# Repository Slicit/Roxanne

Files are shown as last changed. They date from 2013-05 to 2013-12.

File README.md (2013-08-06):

Roxanne
=======

Roxanne is a FFF 3D Printer, Inspired by Reprap, Foldarap, And MendelMax

A 3D PDF is available in /manual (3D Assembly & PDF not up-to-date)

=======

*STL Print list, release 1.0*

- (1)Axe_Guide_160mm.STL
- (1)Axe_Guide_160mm_Bearing_Vertical.STL
- (1)Bowden_JHead_Compatible.STL
- (1)Direct_Drive_Extruder.STL
- (1)Direct_Drive_Tightner.stl
- (1)Endstop_Holder_Profile_Y.STL
- (1)Rotary_LCD.STL
- (1)Triple_Fan_Holder_40mm.STL
- (1)XZ_End_Ajustable.STL
- (1)XZ_End_Idler.STL
- (1)X_Carriage.STL
- (1)X_Motor_Plate.STL
- (1)Y_Motor_Bottom.STL
- (1)Y_Motor_Top.STL
- (2)Angle_33.STL
- (2)Angle_57.stl
- (2)Captive_M6_Nut.STL
- (2)Endstop_Holder_Profile_XZ.STL
- (2)Fan_Support_40mm.STL
- (2)X_End_Idler.STL
- (2)Z_Motor_Plate.STL
- (4)LM10UU_Holder.STL
- (4)Print_Surface_Holder.STL

=======
Thanks to:
- lv-esad
- wooz_

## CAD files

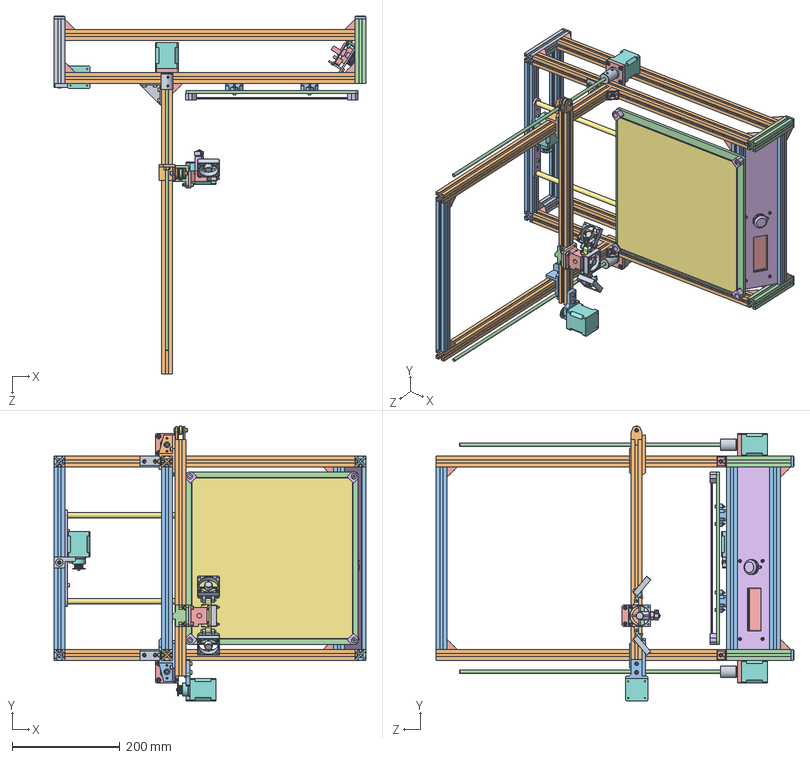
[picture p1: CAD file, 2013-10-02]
sources/solidworks/Roxanne_r2.SLDASM
580.0 x 511.0 x 665.0 mm
Profil_Alu_20x20_2-120mm x 2
Profil_Alu_20x20_540mm x 6
Profil_Alu_20x20_340mm x 5
Profil_Alu_20x20_120mm x 2
Z_Motor_Plate x 2
Axe_Guide_160mm
Rod_500mm x 2
Nema17_48mm x 4
Z_Coupler_5_6 x 2
Profil_Alu_20x20_440mm
Stamp_Foot x 4
6mm_Threaded_Rod_Simple x 2
Angle_2020 x 20
LCD_Plate
socket head cap screw_am x 101
Pulley x 2
Angle_2040 x 2
X_End_Idler x 2
X_Motor_Plate_v2
instrument ball bearing_68_am
RRD_LCD_Smart_Controller
Rotary_LCD
hex nut style 2_am x 4
Reset_Button
Axe_Guide_160mm_Bearing_Vertical
LM10UU x 4
LM10UU_Holder_Higher x 4
Wood_Bed_Simplified
hex nut style 1_am x 20
Glass_Holder x 4
Mirror_Build_Plate
Y_Motor_Bottom
Y_Motor_Top
X-End-Idler-V1
X-End-Motor-V1
X-Carriage-V4
Bowden_JHead_V2
JHead_MKVB
Triple_Fan_Holder_40mm
Support_Ventilateur_1 x 2
Fan_40mm x 3

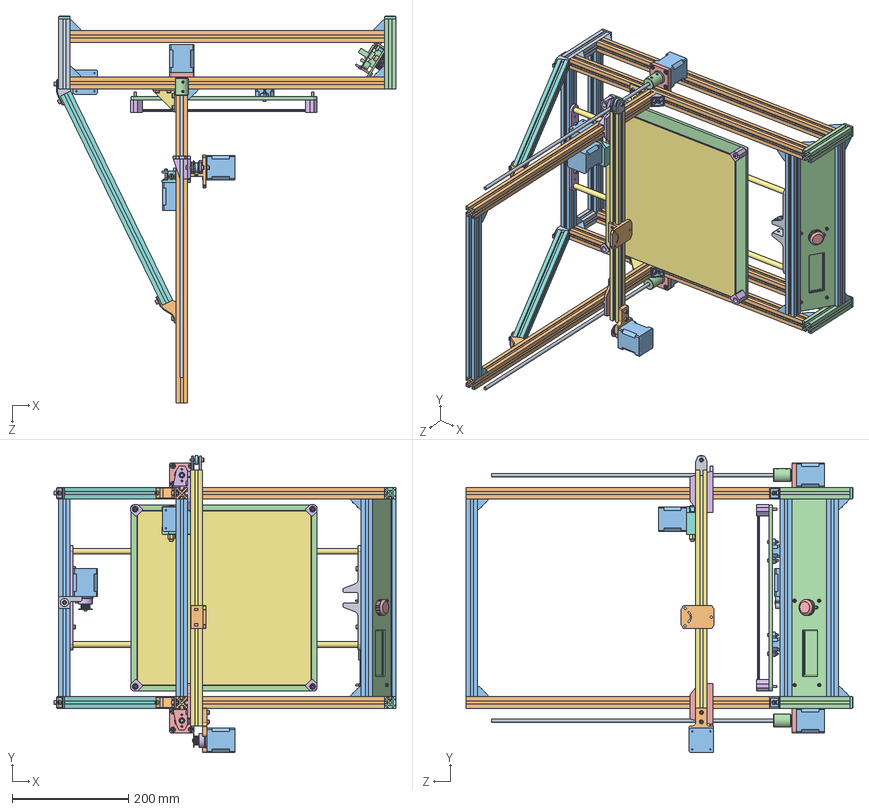
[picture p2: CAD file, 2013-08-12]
sources/solidworks/Roxanne_v1.SLDASM
587.9 x 511.0 x 665.0 mm
Profil_Alu_20x20_2-120mm x 2
Profil_Alu_20x20_540mm x 6
Profil_Alu_20x20_340mm x 5
Profil_Alu_20x20_120mm x 2
Z_Motor_Plate x 2
Axe_Guide_160mm
Rod_500mm x 2
Profil_Alu_20x20_400mm x 2
Angle_33 x 2
Angle_57 x 2
Nema17_48mm x 5
Z_Coupler_5_6 x 2
Router_XZ_Left_V2
Router_XZ_Right_V2
Profil_Alu_20x20_440mm
Stamp_Foot x 4
6mm_Threaded_Rod_Simple x 2
X_Carriage_v3
Angle_2020 x 20
LCD_Plate
socket head cap screw_am x 107
Pulley x 2
Angle_2040 x 2
Direct_Drive_Extruder_v2
X_End_Idler x 2
X_Motor_Plate_v2
instrument ball bearing_68_am
RRD_LCD_Smart_Controller
Rotary_LCD
hex nut style 2_am x 4
Pneufit_4mm_OD
Reset_Button
Axe_Guide_160mm_Bearing_Vertical
LM10UU x 4
LM10UU_Holder_Higher x 4
Wood_Bed_Simplified
hex nut style 1_am x 8
Glass_Holder x 4
Mirror_Build_Plate
Y_Motor_Bottom
Y_Motor_Top

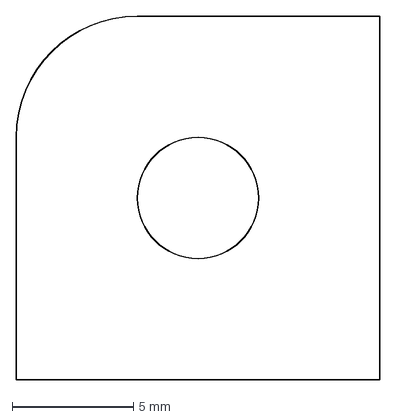
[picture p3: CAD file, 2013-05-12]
sources/lasercut/Spacer.DXF
15.0 x 15.0 mm

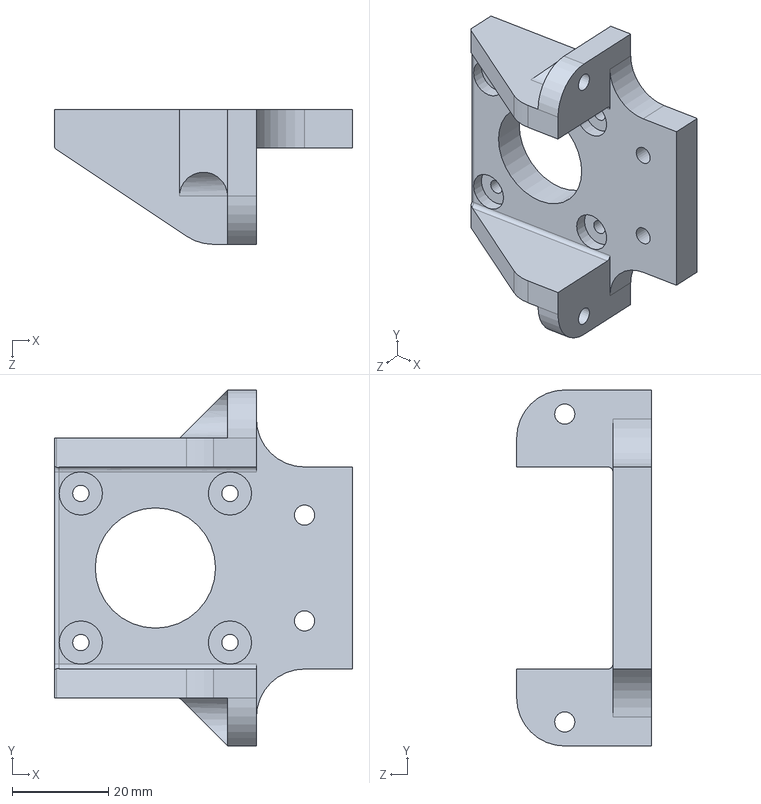
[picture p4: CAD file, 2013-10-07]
sources/solidworks/Z_Motor_Plate_v2.SLDPRT
62.0 x 74.0 x 28.0 mm

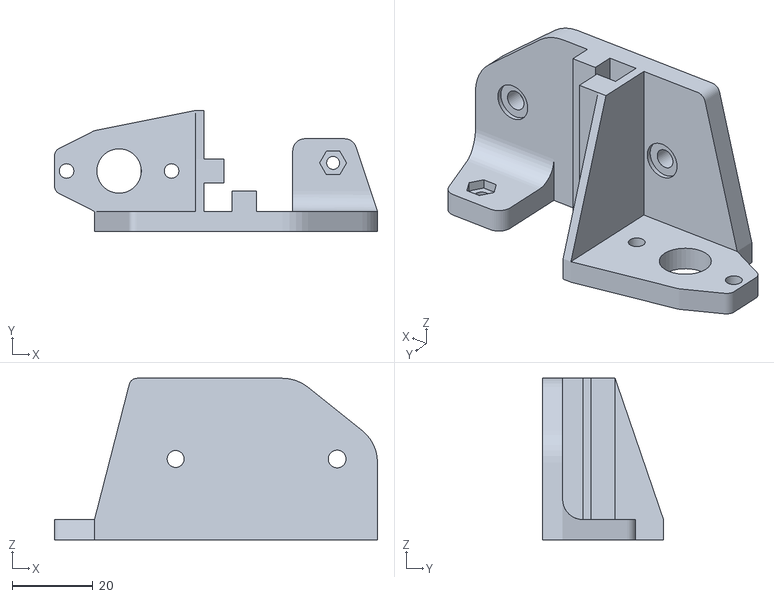
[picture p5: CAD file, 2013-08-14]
sources/stl/rev1/Router_XZ_Left_V2_Larger.STL
80.0 x 30.0 x 40.0

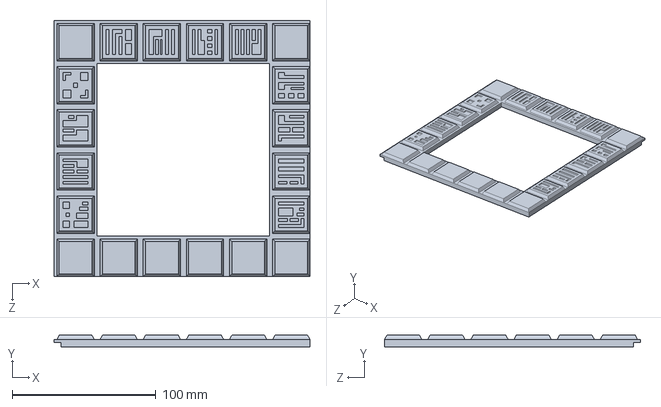
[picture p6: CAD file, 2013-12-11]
sources/stl/telchak.SLDPRT
178.0 x 8.00 x 178.0 mm

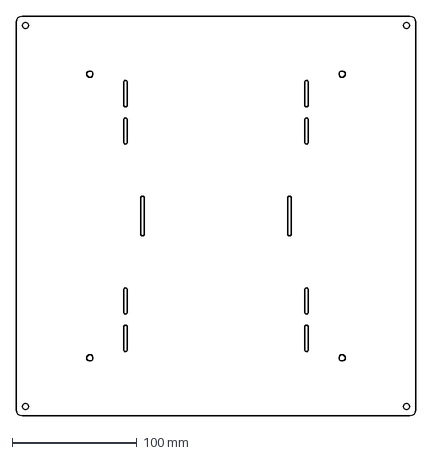
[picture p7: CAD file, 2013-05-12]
sources/lasercut/Bed.DXF
320.0 x 320.0 mm

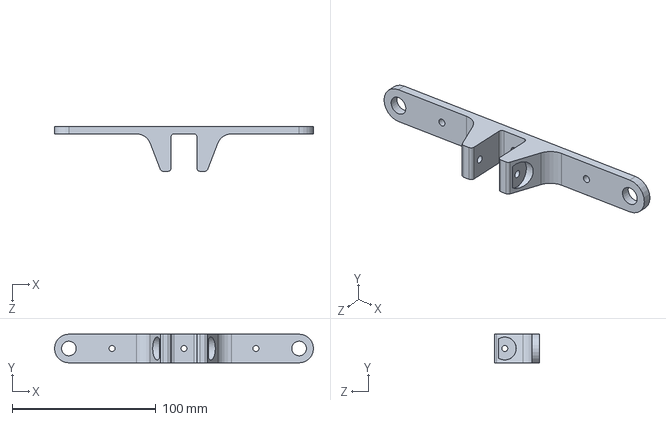
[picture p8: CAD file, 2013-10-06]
sources/solidworks/Axe_Guide_160mm_Bearing_Vertical.SLDPRT
180.0 x 20.0 x 31.0 mm

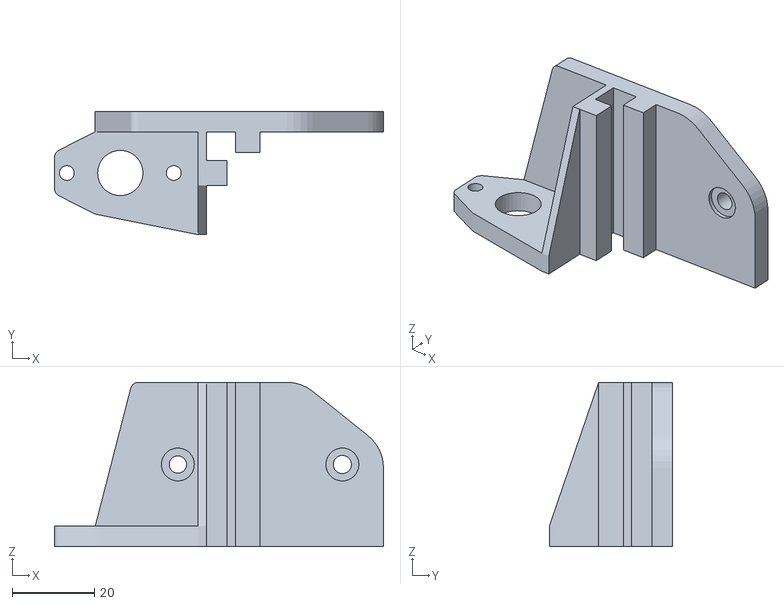
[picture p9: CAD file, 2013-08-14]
sources/stl/rev1/Router_XZ_Right_V3_Larger.STL
80.0 x 30.0 x 40.0

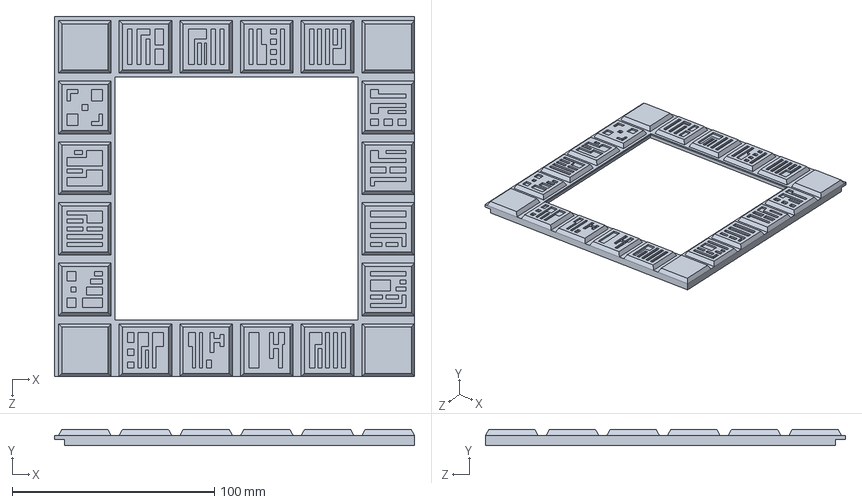
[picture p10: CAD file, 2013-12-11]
sources/stl/telchak2.SLDPRT
178.0 x 8.00 x 178.0 mm

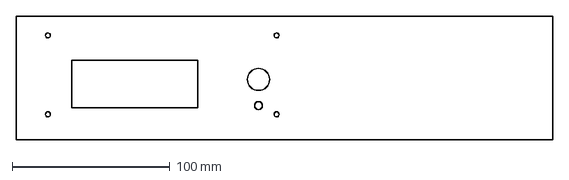
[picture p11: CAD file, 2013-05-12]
sources/lasercut/LCD_Facade_Plate.DXF
340.0 x 78.0 mm

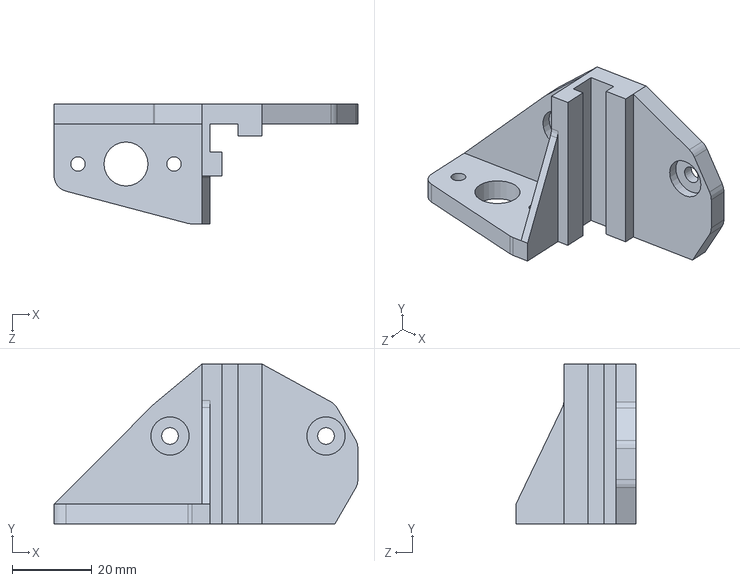
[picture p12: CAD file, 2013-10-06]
sources/solidworks/X-End_Motor_V2.SLDPRT
76.0 x 40.0 x 30.0 mm

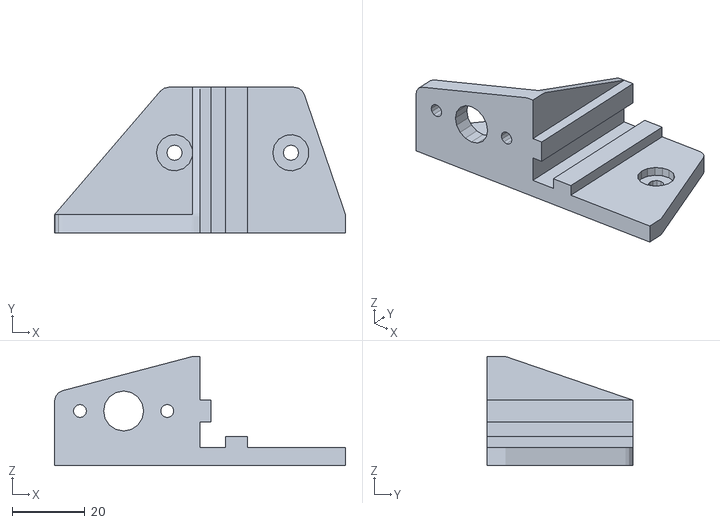
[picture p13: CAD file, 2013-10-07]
sources/stl/(1)X-End-Right (mirrored).stl
80.0 x 40.0 x 30.0

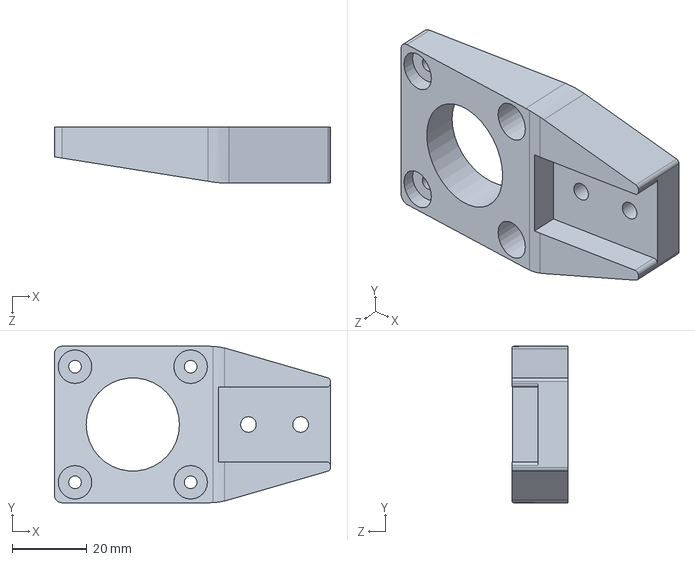
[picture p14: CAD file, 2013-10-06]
sources/solidworks/X_Motor_Plate_v3.SLDPRT
74.0 x 42.0 x 15.0 mm

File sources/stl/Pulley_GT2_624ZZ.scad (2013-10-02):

// Parametric Pulley with multiple belt profiles
// by droftarts January 2012

// Based on pulleys by:
// http://www.thingiverse.com/thing:11256 by me!
// https://github.com/prusajr/PrusaMendel by Josef Prusa
// http://www.thingiverse.com/thing:3104 by GilesBathgate
// http://www.thingiverse.com/thing:2079 by nophead

// dxf tooth data from http://oem.cadregister.com/asp/PPOW_Entry.asp?company=915217&elementID=07807803/METRIC/URETH/WV0025/F
// pulley diameter checked and modelled from data at http://www.sdp-si.com/D265/HTML/D265T016.html

/**
 * @name Pulley
 * @category Printed
 * @using 1 x m3 nut, normal or nyloc
 * @using 1 x m3x10 set screw or 1 x m3x8 grub screw
 */


// tuneable constants

teeth = 30;			// Number of teeth, standard Mendel T5 belt = 8, gives Outside Diameter of 11.88mm
profile = 12;		// 1=MXL 2=40DP 3=XL 4=H 5=T2.5 6=T5 7=T10 8=AT5 9=HTD_3mm 10=HTD_5mm 11=HTD_8mm 12=GT2_2mm 13=GT2_3mm 14=GT2_5mm

motor_shaft = 13.2;	// NEMA17 motor shaft exact diameter = 5
m3_dia = 3.2;		// 3mm hole diameter
m3_nut_hex = 1;		// 1 for hex, 0 for square nut
m3_nut_flats = 5.7;	// normal M3 hex nut exact width = 5.5
m3_nut_depth = 2.7;	// normal M3 hex nut exact depth = 2.4, nyloc = 4

retainer = 1;		// Belt retainer above teeth, 0 = No, 1 = Yes
retainer_ht = 1;	// height of retainer flange over pulley, standard = 1.5
idler = 1;			// Belt retainer below teeth, 0 = No, 1 = Yes
idler_ht = 1;		// height of idler flange over pulley, standard = 1.5

pulley_t_ht = 6;	// length of toothed part of pulley, standard = 12
pulley_b_ht = idler_ht;		// pulley base height, standard = 8. Set to same as idler_ht if you want an idler but no pulley.
pulley_b_dia = 20;	// pulley base diameter, standard = 20
no_of_nuts = 1;		// number of captive nuts required, standard = 1
nut_angle = 90;		// angle between nuts, standard = 90
nut_shaft_distance = 1.2;	// distance between inner face of nut and shaft, can be negative.


//	********************************
//	** Scaling tooth for good fit **
//	********************************
/*	To improve fit of belt to pulley, set the following constant. Decrease or increase by 0.1mm at a time. We are modelling the *BELT* tooth here, not the tooth on the pulley. Increasing the number will *decrease* the pulley tooth size. Increasing the tooth width will also scale proportionately the tooth depth, to maintain the shape of the tooth, and increase how far into the pulley the tooth is indented. Can be negative */

additional_tooth_width = 0.3; //mm

//	If you need more tooth depth than this provides, adjust the following constant. However, this will cause the shape of the tooth to change.

additional_tooth_depth = 0.2; //mm

// calculated constants

nut_elevation = pulley_b_ht/2;
m3_nut_points = 2*((m3_nut_flats/2)/cos(30)); // This is needed for the nut trap

// The following set the pulley diameter for a given number of teeth

MXL_pulley_dia = tooth_spacing (2.032,0.254);
40DP_pulley_dia = tooth_spacing (2.07264,0.1778);
XL_pulley_dia = tooth_spacing (5.08,0.254);
H_pulley_dia = tooth_spacing (9.525,0.381);
T2_5_pulley_dia = tooth_spaceing_curvefit (0.7467,0.796,1.026);
T5_pulley_dia = tooth_spaceing_curvefit (0.6523,1.591,1.064);
T10_pulley_dia = tooth_spacing (10,0.93);
AT5_pulley_dia = tooth_spaceing_curvefit (0.6523,1.591,1.064);
HTD_3mm_pulley_dia = tooth_spacing (3,0.381);
HTD_5mm_pulley_dia = tooth_spacing (5,0.5715);
HTD_8mm_pulley_dia = tooth_spacing (8,0.6858);
GT2_2mm_pulley_dia = tooth_spacing (2,0.254);
GT2_3mm_pulley_dia = tooth_spacing (3,0.381);
GT2_5mm_pulley_dia = tooth_spacing (5,0.5715);

// The following calls the pulley creation part, and passes the pulley diameter and tooth width to that module

if ( profile == 1 ) { pulley ( "MXL" , MXL_pulley_dia , 0.508 , 1.321 ); }
if ( profile == 2 ) { pulley ( "40 D.P." , 40DP_pulley_dia , 0.457 , 1.226 ); }
if ( profile == 3 ) { pulley ( "XL" , XL_pulley_dia , 1.27, 3.051 ); }
if ( profile == 4 ) { pulley ( "H" , H_pulley_dia ,1.905 , 5.359 ); }
if ( profile == 5 ) { pulley ( "T2.5" , T2_5_pulley_dia , 0.7 , 1.678 ); }
if ( profile == 6 ) { pulley ( "T5" , T5_pulley_dia , 1.19 , 3.264 ); }
if ( profile == 7 ) { pulley ( "T10" , T10_pulley_dia , 2.5 , 6.13 ); }
if ( profile == 8 ) { pulley ( "AT5" , AT5_pulley_dia , 1.19 , 4.268 ); }
if ( profile == 9 ) { pulley ( "HTD 3mm" , HTD_3mm_pulley_dia , 1.289 , 2.27 ); }
if ( profile == 10 ) { pulley ( "HTD 5mm" , HTD_5mm_pulley_dia , 2.199 , 3.781 ); }
if ( profile == 11 ) { pulley ( "HTD 8mm" , HTD_8mm_pulley_dia , 3.607 , 6.603 ); }
if ( profile == 12 ) { pulley ( "GT2 2mm" , GT2_2mm_pulley_dia , 0.764 , 1.494 ); }
if ( profile == 13 ) { pulley ( "GT2 3mm" , GT2_3mm_pulley_dia , 1.169 , 2.31 ); }
if ( profile == 14 ) { pulley ( "GT2 5mm" , GT2_5mm_pulley_dia , 1.969 , 3.952 ); }

// Functions

function tooth_spaceing_curvefit (b,c,d)
	= ((c * pow(teeth,d)) / (b + pow(teeth,d))) * teeth ;

function tooth_spacing(tooth_pitch,pitch_line_offset)
	= (2*((teeth*tooth_pitch)/(3.14159265*2)-pitch_line_offset)) ;

// Main Module

module pulley( belt_type , pulley_OD , tooth_depth , tooth_width )
	{
	echo (str("Belt type = ",belt_type,"; Number of teeth = ",teeth,"; Pulley Outside Diameter = ",pulley_OD,"mm "));
	tooth_distance_from_centre = sqrt( pow(pulley_OD/2,2) - pow((tooth_width+additional_tooth_width)/2,2));
	tooth_width_scale = (tooth_width + additional_tooth_width ) / tooth_width;
	tooth_depth_scale = ((tooth_depth + additional_tooth_depth ) / tooth_depth) ;


//	************************************************************************
//	*** uncomment the following line if pulley is wider than puller base ***
//	************************************************************************

//	translate ([0,0, pulley_b_ht + pulley_t_ht + retainer_ht ]) rotate ([0,180,0])

	difference()
	 {	 
		union()
		{
			//base
	
			if ( pulley_b_ht < 2 ) { echo ("CAN'T DRAW PULLEY BASE, HEIGHT LESS THAN 2!!!"); } else {
				rotate_extrude($fn=pulley_b_dia*2)
				{
						square([pulley_b_dia/2-1,pulley_b_ht]);
						square([pulley_b_dia/2,pulley_b_ht-1]);
						translate([pulley_b_dia/2-1,pulley_b_ht-1]) circle(1);
				}
			}
	
		difference()
			{
			//shaft - diameter is outside diameter of pulley
			
			translate([0,0,pulley_b_ht]) 
			rotate ([0,0,360/(teeth*4)]) 
			cylinder(r=pulley_OD/2,h=pulley_t_ht, $fn=teeth*4);
	
			//teeth - cut out of shaft
		
			for(i=[1:teeth]) 
			rotate([0,0,i*(360/teeth)])
			translate([0,-tooth_distance_from_centre,pulley_b_ht -1]) 
			scale ([ tooth_width_scale , tooth_depth_scale , 1 ]) 
			{
			if ( profile == 1 ) { MXL();}
			if ( profile == 2 ) { 40DP();}
			if ( profile == 3 ) { XL();}
			if ( profile == 4 ) { H();}
			if ( profile == 5 ) { T2_5();}
			if ( profile == 6 ) { T5();}
			if ( profile == 7 ) { T10();}
			if ( profile == 8 ) { AT5();}
			if ( profile == 9 ) { HTD_3mm();}
			if ( profile == 10 ) { HTD_5mm();}
			if ( profile == 11 ) { HTD_8mm();}
			if ( profile == 12 ) { GT2_2mm();}
			if ( profile == 13 ) { GT2_3mm();}
			if ( profile == 14 ) { GT2_5mm();}
			}

			}
			
		//belt retainer / idler
		if ( retainer > 0 ) {translate ([0,0, pulley_b_ht + pulley_t_ht ]) 
		rotate_extrude($fn=teeth*4)  
		polygon([[0,0],[pulley_OD/2,0],[pulley_OD/2 + retainer_ht , retainer_ht],[0 , retainer_ht],[0,0]]);}
		
		if ( idler > 0 ) {translate ([0,0, pulley_b_ht - idler_ht ]) 
		rotate_extrude($fn=teeth*4)  
		polygon([[0,0],[pulley_OD/2 + idler_ht,0],[pulley_OD/2 , idler_ht],[0 , idler_ht],[0,0]]);}
	
		}
	   
		//hole for motor shaft
		translate([0,0,-1])cylinder(r=motor_shaft/2,h=pulley_b_ht + pulley_t_ht + retainer_ht + 2,$fn=motor_shaft*4);
				
		//captive nut and grub screw holes
	
		if ( pulley_b_ht < m3_nut_flats ) { echo ("CAN'T DRAW CAPTIVE NUTS, HEIGHT LESS THAN NUT DIAMETER!!!"); } else {
		if ( (pulley_b_dia - motor_shaft)/2 < m3_nut_depth + 3 ) { echo ("CAN'T DRAW CAPTIVE NUTS, DIAMETER TOO SMALL FOR NUT DEPTH!!!"); } else {
	
			for(j=[1:no_of_nuts]) rotate([0,0,j*nut_angle])
			translate([0,0,nut_elevation])rotate([90,0,0])
	
			union()
			{
				//entrance
				translate([0,-pulley_b_ht/4-0.5,motor_shaft/2+m3_nut_depth/2+nut_shaft_distance]) cube([m3_nut_flats,pulley_b_ht/2+1,m3_nut_depth],center=true);
	
				//nut
				if ( m3_nut_hex > 0 )
					{
						// hex nut
						translate([0,0.25,motor_shaft/2+m3_nut_depth/2+nut_shaft_distance]) rotate([0,0,30]) cylinder(r=m3_nut_points/2,h=m3_nut_depth,center=true,$fn=6);
					} else {
						// square nut
						translate([0,0.25,motor_shaft/2+m3_nut_depth/2+nut_shaft_distance]) cube([m3_nut_flats,m3_nut_flats,m3_nut_depth],center=true);
					}
	
				//grub screw hole
				rotate([0,0,22.5])cylinder(r=m3_dia/2,h=pulley_b_dia/2+1,$fn=8);
			}
		}}
	 }
	   
	}


// Tooth profile modules
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

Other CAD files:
sources/stl/Axe_Guide_160mm_Bearing_Vertical_v2.STL
sources/stl/rev1/X_Carriage_v3.STL
sources/solidworks/X-End_Motor_Adj_V2.SLDPRT
sources/stl/(2)Pulley_T25_624ZZ.stl
archives/sources_solidworks/6mm_Threaded_Rod_Simple.SLDPRT
archives/sources_solidworks/Aluminium_Bed.SLDPRT
archives/sources_solidworks/Angle_2020.SLDPRT
archives/sources_solidworks/Angle_2040.SLDPRT
archives/sources_solidworks/Angle_33.SLDPRT
archives/sources_solidworks/Angle_57.SLDPRT
archives/sources_solidworks/Angle_Holder.SLDPRT
archives/sources_solidworks/Axe_Guide_140mm.SLDPRT
archives/sources_solidworks/Axe_Guide_140mm_Bearing.SLDPRT
archives/sources_solidworks/Axe_Guide_160mm.SLDPRT
archives/sources_solidworks/Axe_Guide_160mm_Bearing.SLDPRT
archives/sources_solidworks/Bowden_JHead_V1.SLDPRT
archives/sources_solidworks/Bowden_JHead_V2.SLDPRT
archives/sources_solidworks/Captive_Acme17_Nut.SLDPRT
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

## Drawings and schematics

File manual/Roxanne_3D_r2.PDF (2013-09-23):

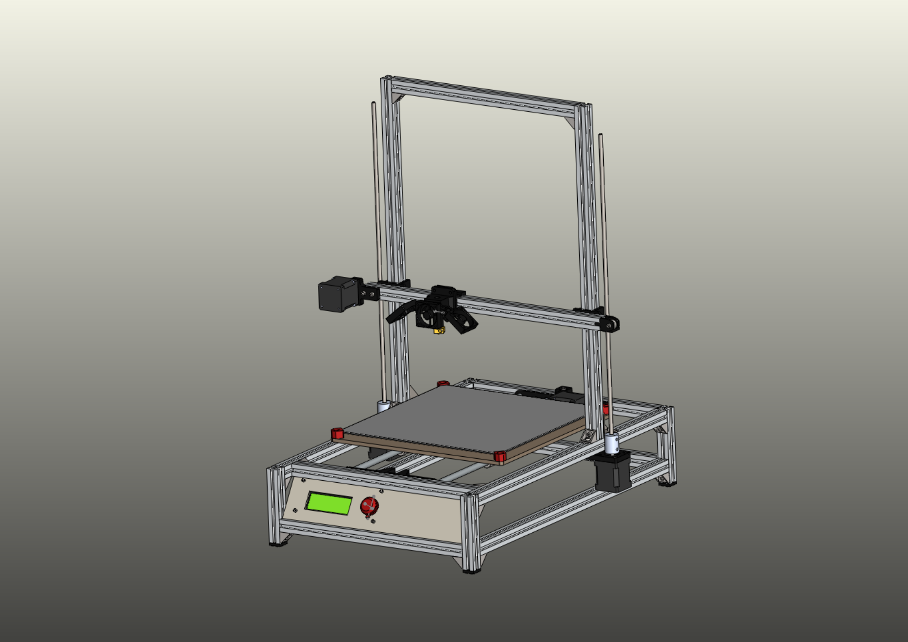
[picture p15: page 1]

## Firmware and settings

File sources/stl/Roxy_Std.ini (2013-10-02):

[profile]
filament_diameter = 1.75
nozzle_size = 0.35
wall_thickness = 0.39
layer_height = 0.25
retraction_enable = True
solid_layer_thickness = 0.39
fill_density = 30
print_speed = 100
print_temperature = 220
print_bed_temperature = 55
support = None
enable_raft = False
filament_density = 1.00
skirt_line_count = 3
skirt_gap = 3.0
retraction_min_travel = 5.0
retraction_speed = 50.0
retraction_amount = 4.5
retraction_extra = 0.0
travel_speed = 120
max_z_speed = 3.0
bottom_layer_speed = 40
cool_min_layer_time = 5
fan_enabled = True
bottom_thickness = 0.2
enable_skin = False
plugin_config = (lp1
	.
flip_x = False
flip_y = False
flip_z = False
swap_xz = False
swap_yz = True
model_scale = 1.0
model_rotate_base = 0
extra_base_wall_thickness = 0.0
cool_min_feedrate = 10
fan_layer = 1
fan_speed = 100
fan_speed_max = 100
raft_margin = 5
raft_base_material_amount = 100
raft_interface_material_amount = 100
support_rate = 50
support_distance = 0.5
infill_type = Line
solid_top = True
fill_overlap = 15
bridge_speed = 100
sequence = Loops > Perimeter > Infill
force_first_layer_sequence = True
joris = False
retract_on_jumps_only = True
hop_on_move = False

[alterations]
start.gcode = ;Sliced {filename} at: {day} {date} {time}
	;Basic settings: Layer height: {layer_height} Walls: {wall_thickness} Fill: {fill_density}
	;Print time: {print_time}
	;Filament used: {filament_amount}m {filament_weight}g
	;Filament cost: {filament_cost}
	G21        ;metric values
	G90        ;absolute positioning
	M107       ;start with the fan off
	G28 X0 Y0  ;move X/Y to min endstops
	G28 Z0     ;move Z to min endstops
	G92 X0 Y0 Z0 E0         ;reset software position to front/left/z=0.0
	G1 Z15.0 F{max_z_speed} ;move the platform down 15mm
	G92 E0                  ;zero the extruded length
	G1 F200 E3              ;extrude 3mm of feed stock
	G92 E0                  ;zero the extruded length again
	G1 F{travel_speed}
end.gcode = ;End GCode
	M104 S0                     ;extruder heater off
	M140 S0                     ;heated bed heater off (if you have it)
	G91                                    ;relative positioning
	G1 E-1 F300                            ;retract the filament a bit before lifting the nozzle, to release some of the pressure
	G1 Z+0.5 E-5 X-20 Y-20 F{travel_speed} ;move Z up a bit and retract filament even more
	G28 X0 Y0                              ;move X/Y to min endstops, so the head is out of the way
	M84                         ;steppers off
	G90                         ;absolute positioning
nextobject.gcode = ;Move to next object on the platform. clear_z is the minimal z height we need to make sure we do not hit any objects.
	G92 E0
	G91                                    ;relative positioning
	G1 E-1 F300                            ;retract the filament a bit before lifting the nozzle, to release some of the pressure
	G1 Z+0.5 E-5 F{travel_speed}           ;move Z up a bit and retract filament even more
	G90                                    ;absolute positioning
	G1 Z{clear_z} F{max_z_speed}
	G92 E0
	G1 X{object_center_x} Y{object_center_x} F{travel_speed}
	G1 F200 E6
	G92 E0
replace.csv = 

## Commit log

2013-05-11 First STL pack, 3D PDF.
    [Angle_33.STL, Angle_57.stl, Axe_Guide_160mm.STL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]
2013-05-11 Solidworks source files.
    [6mm_Threaded_Rod_Simple.SLDPRT, Aluminium_Bed.SLDPRT, Angle_2020.SLDPRT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]
2013-05-12 Dual Extruder update, X-Carriage
    [Dual_Extruder_Jhead.stl, Dual_Extruder_Jhead_v2.SLDPRT, Fan_Holder.SLDPRT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]
2013-05-12 Update X-Carriage & STL
    [X_Carriage.STL, X_Carriage_v3.SLDPRT]
2013-05-12 LCD Plate & DXF
    [LCD_Facade_Plate.DXF, LCD_Plate.SLDPRT, Roxanne.SLDASM]
2013-05-12 Bed & Spacers
    [Bed.DXF, Spacer.DXF, Spacer.SLDPRT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]
2013-05-12 Readme update, STL Rename.
    [YZ_Motor_Plate.STL]
2013-05-15 STL Fix, Endstop For X Z
    [Endstop_Holder_Profile_XZ.SLDPRT]
2013-05-15 STL Endstop Holder
    [Endstop_Holder_Profile_XZ.STL]
2013-05-15 Endstop Y
    [Endstop_Holder_Profile_Y.SLDPRT, Endstop_Holder_Profile_Y.STL]
2013-05-15 Captives nuts
    [Captive_M6_Nut.SLDPRT, Captive_M8_Nut.SLDPRT, Captive_M8_Nut.STL]
2013-05-15 Acme 17 nut
    [Captive_Acme17_Nut.SLDPRT, Captive_Acme17_Nut.STL]
2013-05-15 Fixed STLs
    [Endstop_Holder_Profile_XZ.STL, Endstop_Holder_Profile_Y.STL]
2013-05-15 Fixed X-Carriage STL
    [X_Carriage.STL]
2013-05-15 Captive Nut M6
    [Captive_M6_Nut.STL]
2013-05-15 Idlers, STL, EndstopHolder nopcb
    [Dual_624.SLDPRT, Dual_624.STL, Endstop_Nopcb_Holder_Profile_XZ.SLDPRT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]
2013-05-18 Update Assembly, New parts.
    [Angle_2040.SLDPRT, Direct_Drive_Extruder_v2.SLDPRT, Direct_Drive_Extruder_v2.STL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]
2013-05-18 New Direct Drive Extruder, X-Motor Revised
    Also removed old X-Idlers
    [Direct_Drive_Extruder_v2.SLDPRT, Dual_624.SLDPRT, Roxanne.SLDASM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]
2013-05-18 Fixed Extruder STL
    [Direct_Drive_Extruder_v2.STL]
2013-05-19 Update STL position
    [X_End_Idler.STL]
2013-05-19 RRD LCD Smart Controller, Extruder, Assembly
    [Angle_33.SLDPRT, Angle_57.SLDPRT, Axe_Guide_160mm.SLDPRT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]
2013-05-19 Update & Pneufits
    [Pneufit_4mm_OD.SLDPRT, Roxanne.SLDASM, Tube_1-Roxanne.sldasm]
2013-05-19 Update Assembly
    [Roxanne.SLDASM]
2013-05-19 Removed old files, Update Readme.
    [Dual_624.STL, Idler_624.STL, X_Motor_Plate.STL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]
2013-05-19 Rotary LCD Button
    [Rotary_LCD.STL]
2013-05-19 Update LCD Panel, Assembly
    [LM10UU.SLDPRT, Reset_Button.SLDPRT, Roxanne.SLDASM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]
2013-05-20 M5 nut, Fixed 120mm Aluminium Extrusion
    [Captive_M5_Nut.SLDPRT, Captive_M5_Nut.STL, Profil_Alu_20x20_120mm.SLDPRT]
2013-05-20 Update dual Extruder
    [Dual_Extruder_Jhead.stl, Fan_Holder.STL, Roxanne.SLDASM]
2013-05-20 Fan Supports
    [Fan_Support_40mm_Model_1.SLDPRT, Fan_Support_40mm_Model_1.STL, Fan_Support_40mm_Model_2.STL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]
2013-06-11 Parts upgrade
    X-End with integrated Z adjustable endstop
    Higher LM10UU Holders to avoid the bolts to hit the frame
    Guide For Y Axis holder (center point, and upgrade for Y motor bolts)
    [Axe_Guide_160mm.SLDPRT, Axe_Guide_160mm.STL, Axe_Guide_160mm_Bearing.SLDPRT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]
2013-06-11 PDF 3D, Assembly
    [Profil_Alu_20x20_2-120mm.SLDPRT, Router_XZ_Right_V2.SLDPRT, Roxanne.SLDASM]
2013-06-12 Fixed STL (netfabb)
    [Axe_Guide_160mm.STL, Axe_Guide_160mm_Bearing.STL, LM10UU_Holder_Higher.STL]
2013-06-12 Update Z Adjustable
    [Router_XZ_Left_V2.SLDPRT, Router_XZ_Left_V2.STL]
2013-06-12 Bowden Jhead v1
    [Bowden_JHead_V1.SLDPRT, Bowden_JHead_V1.STL]
2013-06-12 Updated Z Adjustable
    [Router_XZ_Left_Adjustable_Z.STL, Router_XZ_Left_V2.SLDPRT]
2013-07-10 New Y Belt Path
    [Axe_Guide_160mm_Bearing_Vertical.SLDPRT, Axe_Guide_160mm_Bearing_Vertical.STL, Router_XZ_Right_V2.SLDPRT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]
2013-07-22 Glass Holder
    [Glass_Holder.SLDPRT, Glass_Holder.STL]
2013-07-22 Fixed Glass Holder positionning
    [Glass_Holder.STL]
2013-07-24 Updated Y Holders
    [Axe_Guide_160mm.SLDPRT, Axe_Guide_160mm.STL]
2013-07-25 Fixed adjustable endstop alignment
    [Router_XZ_Left_V2.SLDPRT, Router_XZ_Left_V2.STL]
2013-07-26 Fan Holders, Jhead Fix v4
    [Bowden_JHead_V1.SLDPRT, Bowden_JHead_V2.SLDPRT, Bowden_JHead_V2.STL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]
2013-07-26 Update Fan Holders
    [Triple_Fan_Holder_30mm.SLDPRT, Triple_Fan_Holder_40mm.SLDPRT, Triple_Fan_Holder_40mm.STL]
2013-08-06 Release 1.0 Roxanne (STL)
    [(1)Axe_Guide_160mm.STL, (1)Axe_Guide_160mm_Bearing_Vertical.STL, (1)Bowden_JHead_Compatible.STL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]
2013-08-12 Updated 3D PDF
    [Glass_Holder.SLDPRT, Mirror_Build_Plate.SLDPRT, Router_XZ_Right_V2.SLDPRT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]
2013-08-14 New X-ends
    [Router_XZ_Left_V2_Larger.SLDPRT, Router_XZ_Left_V2_Larger.STL, Router_XZ_Right_V2_Larger.SLDPRT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]
2013-08-18 moved rev1, rev2 in progress
    [(1)X-Carriage.STL, (1)X-End-Idler.STL, (1)X-End-Motor.STL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]
2013-09-23 Roxanne R2, in progress
    New PDF 3D, Roxanne_r2
    [Axe_Guide_160mm.SLDPRT, Axe_Guide_160mm_Bearing_Vertical.SLDPRT, Bowden_JHead_V2.SLDPRT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]
2013-09-25 Updated Parts Endstop Holders, New X/Z Sliders
    [(1)X-Carriage.STL, (1)X-End-Idler.STL, (1)X-End-Motor.STL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]
2013-09-25 Glass holder V2 STL
    [Glass_Holder.SLDPRT, Glass_Holder_V2.STL]
2013-09-25 Nut Holder Bed Level
    [Nut_Holder_Level.SLDPRT, Nut_Holder_Level.STL]
2013-09-25 Test Charn
    [Angle_Holder.SLDPRT, Angle_Holder.STL, Charn_Type_1.SLDPRT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]
2013-10-02 Update X_Idler/End
    [(1)X-End-Idler.STL, (1)X-End-Left.STL, (1)X-End-Motor.STL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]
2013-10-02 Special Files
    [(1)Power-Switch-Plate.STL, (1)Y-Endstop-Holder.STL, (2)Pulley_GT2_624ZZ.stl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]
2013-10-06 new x-motor, upgrade y-idler
    [Axe_Guide_160mm_Bearing_Vertical.SLDPRT, Axe_Guide_160mm_Bearing_Vertical_v2.STL, X-End_Motor_V2.SLDPRT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]
2013-10-06 new re-inforced z
    [Z_Motor_Plate_v2.STL]
2013-10-09 Repaired STL
    [X_Motor_Plate.STL, Z_Motor_Plate_v2.STL]
2013-12-11 Mmoved release 1 sources
    [6mm_Threaded_Rod_Simple.SLDPRT, Aluminium_Bed.SLDPRT, Angle_2020.SLDPRT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]
